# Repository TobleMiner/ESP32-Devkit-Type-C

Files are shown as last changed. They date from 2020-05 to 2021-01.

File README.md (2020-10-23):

ESP32 Devkit Type C
===================

This PCB is a USB Type C enabled ESP32 development board. It is pin-compatible
with the ESP32 Devkit C but sports a slightly decreased width to fit on a
standard breadboard.  
The current revision (Rev E) has been tested and confirmed to work fine.

# Features

* USB Type C
* pin-compatible with ESP32 Devkit
* fits on standard breadboard
* onboard antenna
* jumper to short USB protection diode

Furthermore this board is optimized for JLCPCB assembly, a Chinese SMT PCB
assembly service. All components on this board, except the USB Type C connector,
the push buttons and the pin headers can be assembled by them for around ~$8
including PCB manufacturing and components.

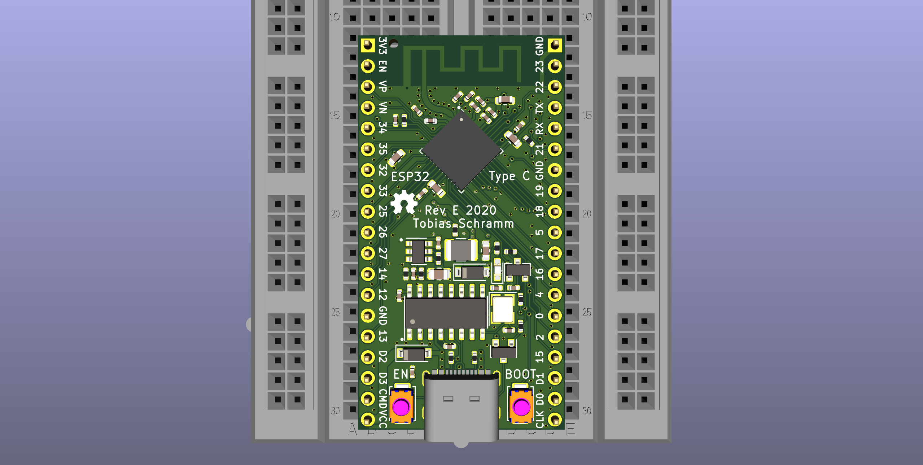
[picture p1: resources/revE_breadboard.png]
Devkit on breadboard


# Assembly

There is an
[interactive HTML BOM](https://tobleminer.github.io/ESP32-Devkit-Type-C/ibom.html)
to help you assemble the board.

Assuming you are using JLCPCB SMT assembly you will need to populate just the
following parts by hand:

| Reference  | Description | LCSC |
|---|---|---|
| J1 | USB Type C connector | [C167321](https://lcsc.com/product-detail/USB-Connectors_Jing-Extension-of-the-Electronic-Co-C167321_C167321.html) |
| SW1, SW2 | RESET/BOOT push button | [C115357](https://lcsc.com/product-detail/Tactile-Switches_ALPS_SKRKAEE020_3-4-2-1-57N_C115357.html) |
| J2, J3 | Pin headers | [C2337](https://lcsc.com/product-detail/Pin-Header-Female-Header_BOOMELE-Boom-Precision-Elec-2-54mm-1x40P_C2337.html) |

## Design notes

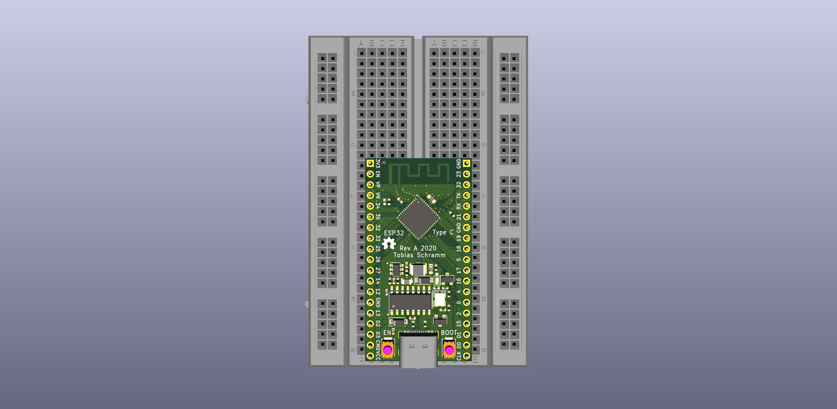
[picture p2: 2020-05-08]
resources/revA_breadboard.png

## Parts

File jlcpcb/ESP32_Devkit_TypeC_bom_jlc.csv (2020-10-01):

Comment | Designator | Footprint | LCSC Part #
10 nF | C1 | C_0402_1005Metric | C15195
22 pF | C2,C4 | C_0402_1005Metric | C1555
10 uF | C3 | C_0805_2012Metric | C15850
100 nF | C5,C7,C14,C15,C16,C6,C18,C17 | C_0402_1005Metric | C1525
22 uF | C8,C13,C24 | C_0603_1608Metric | C59461
1uF | C12 | C_0402_1005Metric | C52923
10uF | C19,C21,C20,C22 | C_0402_1005Metric | C15525
10uF | C23,C25 | C_0603_1608Metric | C19702
B5819W | D2,D1 | D_SOD-123 | C8598
LED | D3 | LED_0603_1608Metric_Castellated | C2286
USB_C_Receptacle_USB2.0 | J1 | USB_C_Receptacle_Palconn_UTC16-G | C167321
4.7 uH | L1 | L_1210_3225Metric | C86070
SS8050 | Q2,Q1 | SOT-23 | C2150
100 kR | R1,R10 | R_0402_1005Metric | C25741
5.1 kR | R3,R2 | R_0402_1005Metric | C25905
330 R | R4,R11,R12 | R_0402_1005Metric | C25104
49.9kR | R5 | R_0402_1005Metric | C25897
15 kR | R6 | R_0402_1005Metric | C25756
5.1kR | R8,R9,R7 | R_0402_1005Metric | C25905
EN | SW1 | SW_Push_SPST_NO_Alps_SKRK | C115357
BOOT | SW2 | SW_Push_SPST_NO_Alps_SKRK | C115357
MP2359 | U1 | SOT-23-6 | C14259
CH340G | U2 | SOIC-16_3.9x9.9mm_P1.27mm | C14267
ESP32-PICO-D4 | U3 | ESP32-Pico-D4 | C193707
12MHz | Y1 | Crystal_SMD_3225-4Pin_3.2x2.5mm | C9002

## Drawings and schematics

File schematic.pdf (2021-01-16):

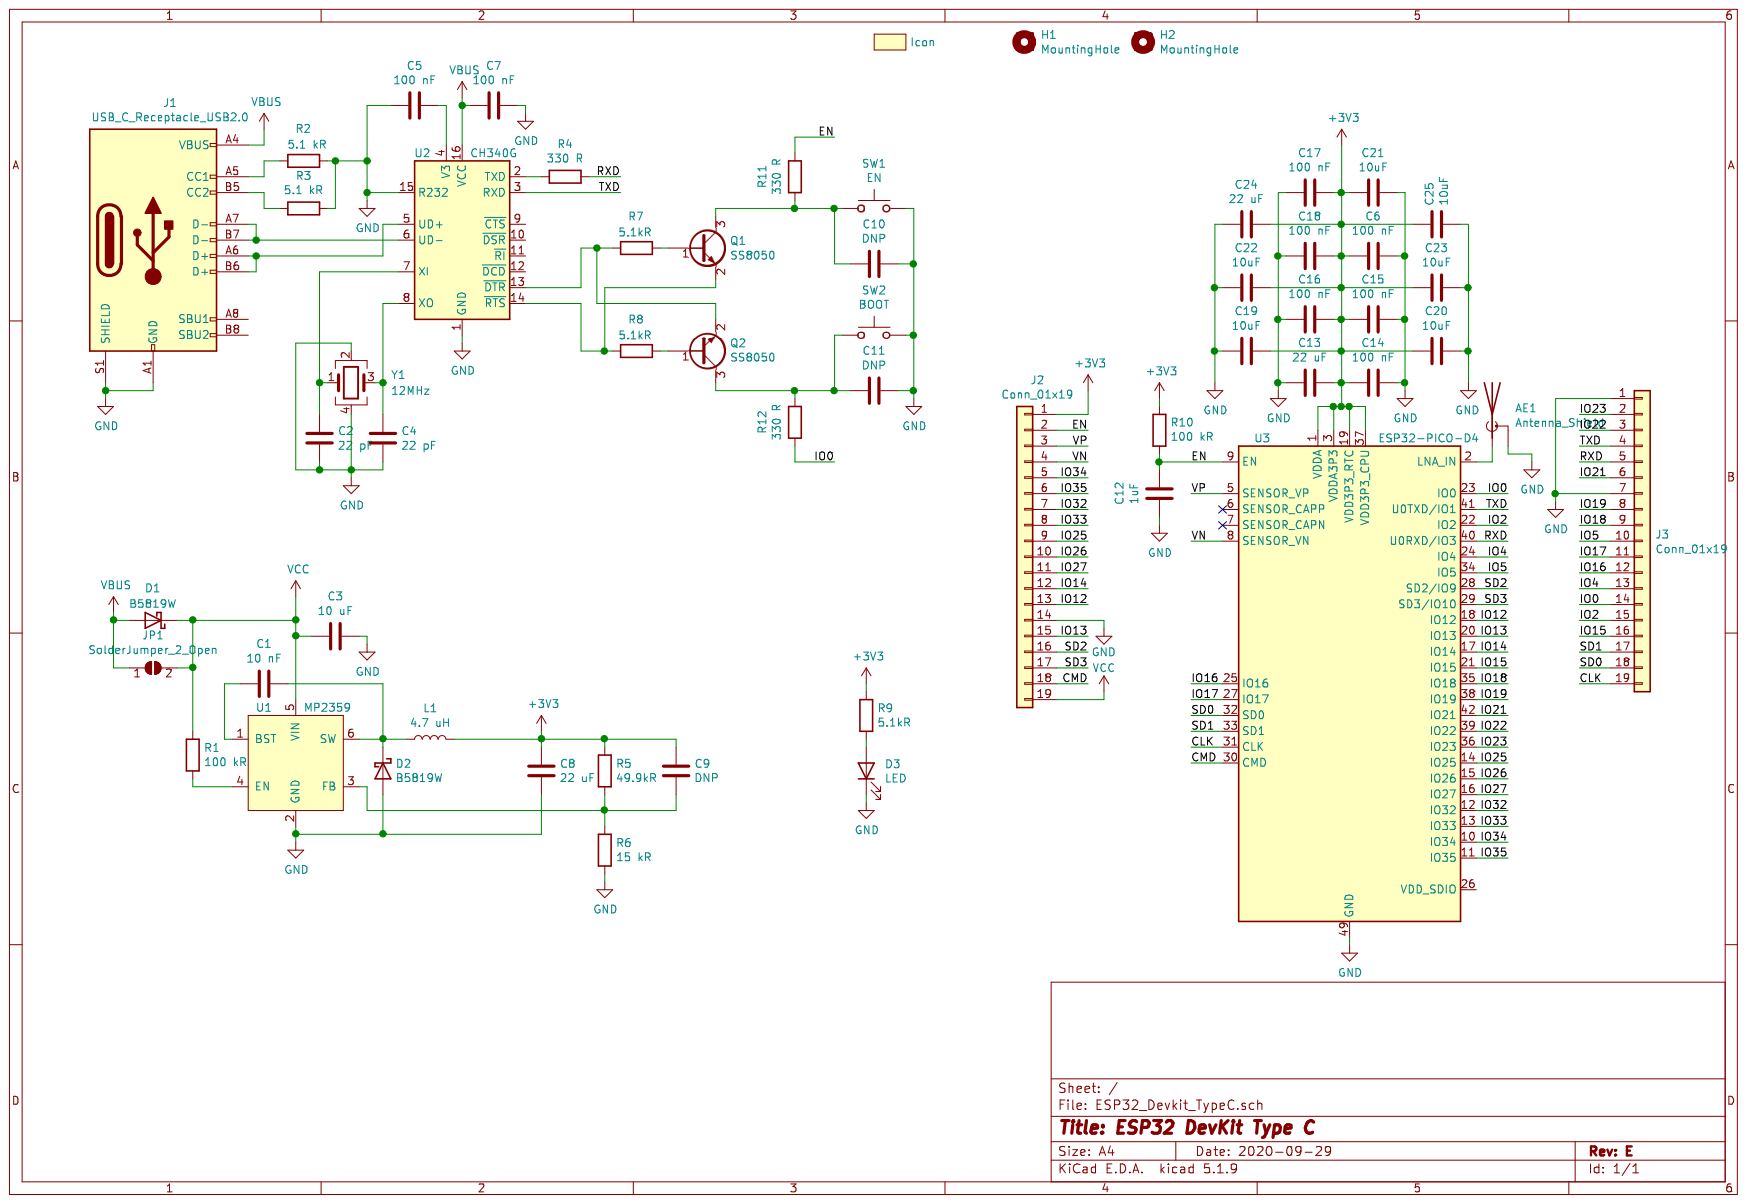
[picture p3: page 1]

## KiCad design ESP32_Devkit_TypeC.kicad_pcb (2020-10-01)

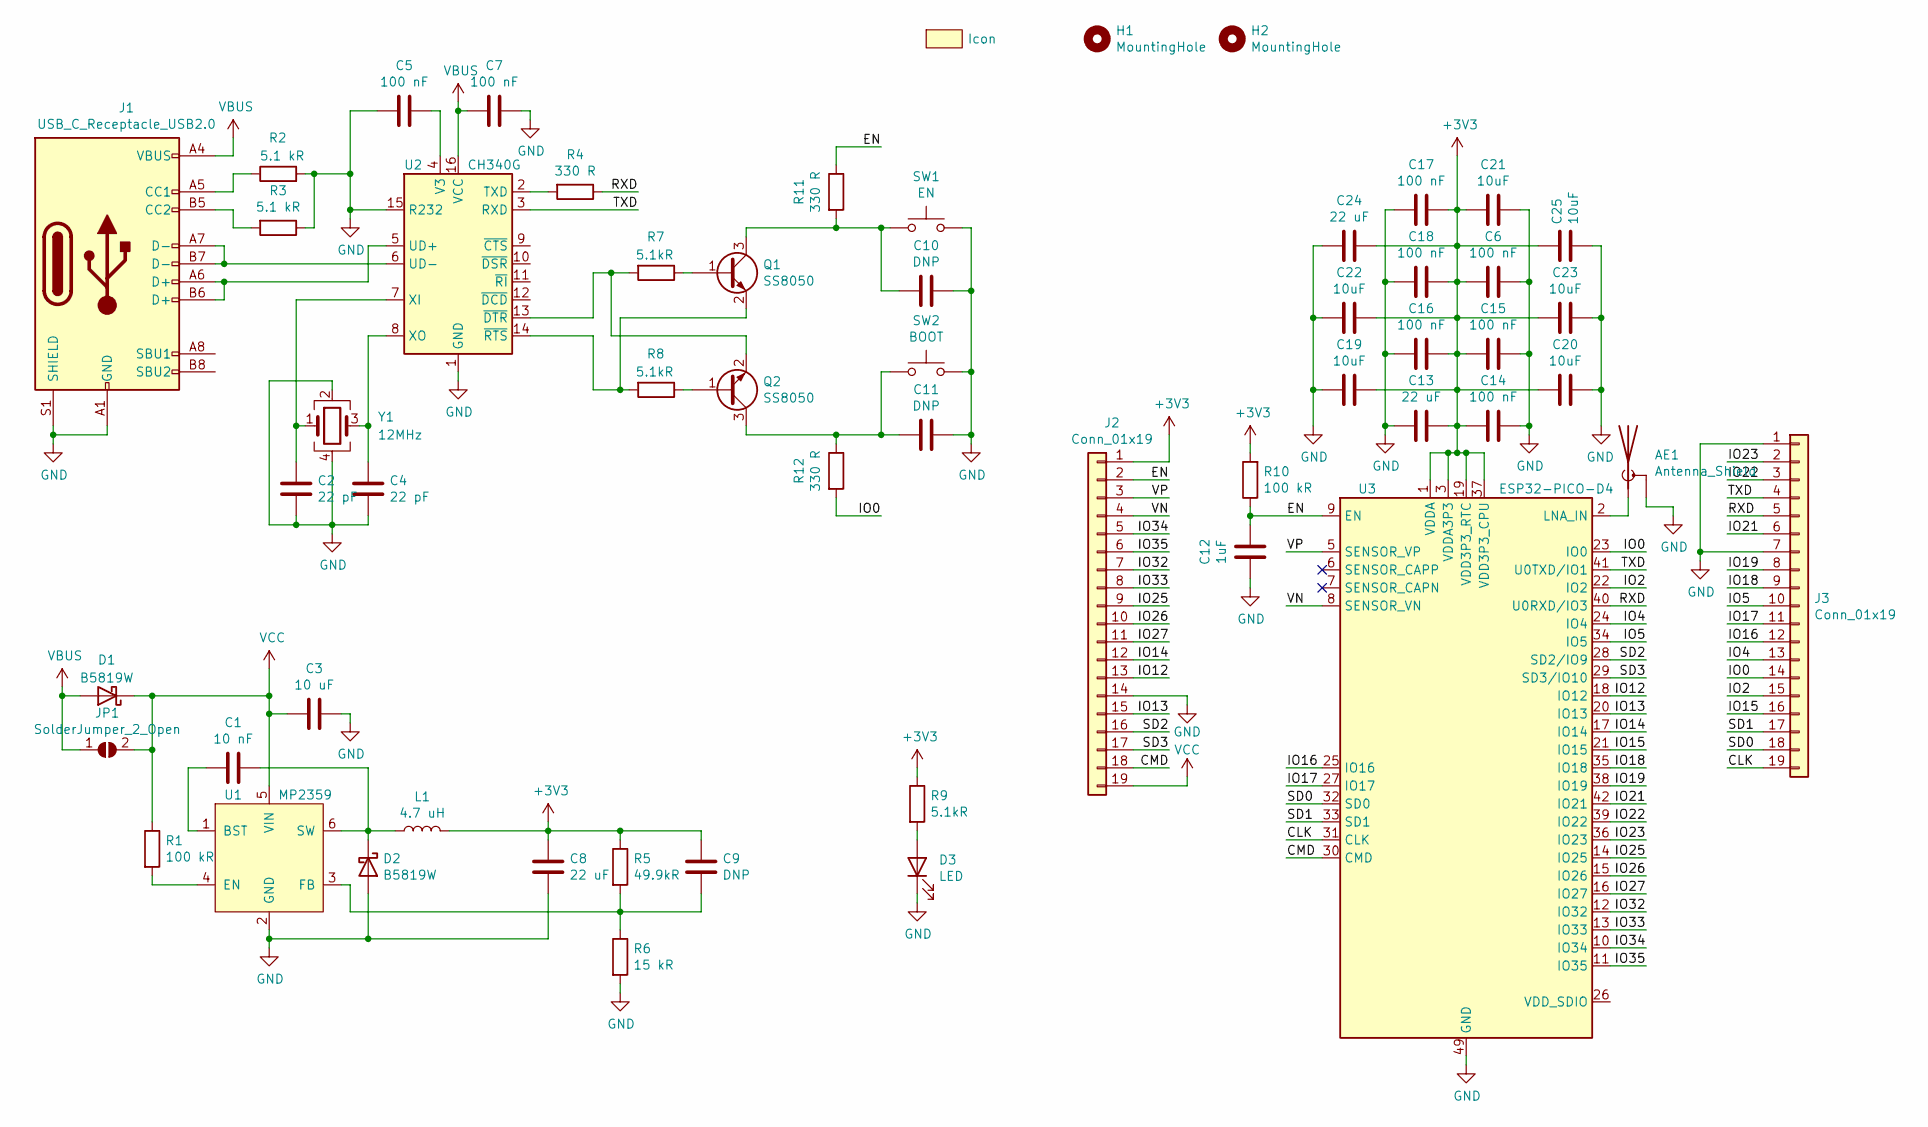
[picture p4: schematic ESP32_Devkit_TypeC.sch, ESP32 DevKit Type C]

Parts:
AE1: Antenna_Shield; Antenna_IFA_2.4GHz_meandered
C1: 10 nF; C_0402_1005Metric; LCSC C15195
C2, C4: 22 pF; C_0402_1005Metric; LCSC C1555
C3: 10 uF; C_0805_2012Metric; LCSC C15850
C5, C6, C7, C14, C15, C16, C17, C18: 100 nF; C_0402_1005Metric; LCSC C1525
C8, C13, C24: 22 uF; C_0603_1608Metric; LCSC C59461
C9, C10, C11: DNP; C_0402_1005Metric
C12: 1uF; C_0402_1005Metric; LCSC C52923
C19, C20, C21, C22: 10uF; C_0402_1005Metric; LCSC C15525
C23, C25: 10uF; C_0603_1608Metric; LCSC C19702
D1, D2: B5819W; D_SOD-123; LCSC C8598
D3: LED; LED_0603_1608Metric_Castellated; LCSC C2286
H1, H2: MountingHole; ToolingHole_JLCSMT
I2: Icon; OSHW_icon_3.3x3
J1: USB_C_Receptacle_USB2.0; USB_C_Receptacle_Palconn_UTC16-G; LCSC C167321
J2, J3: Conn_01x19; PinHeader_1x19_P2.54mm_Vertical
JP1: SolderJumper_2_Open; SolderJumper-2_P1.3mm_Open_Pad1.0x1.5mm
L1: 4.7 uH; L_1210_3225Metric; LCSC C86070
Q1, Q2: SS8050; SOT-23; LCSC C2150
R1, R10: 100 kR; R_0402_1005Metric; LCSC C25741
R2, R3: 5.1 kR; R_0402_1005Metric; LCSC C25905
R4, R11, R12: 330 R; R_0402_1005Metric; LCSC C25104
R5: 49.9kR; R_0402_1005Metric; LCSC C25897
R6: 15 kR; R_0402_1005Metric; LCSC C25756
R7, R8, R9: 5.1kR; R_0402_1005Metric; LCSC C25905
SW1: EN; SW_Push_SPST_NO_Alps_SKRK; LCSC C115357
SW2: BOOT; SW_Push_SPST_NO_Alps_SKRK; LCSC C115357
U1: MP2359; SOT-23-6; LCSC C14259
U2: CH340G; SOIC-16_3.9x9.9mm_P1.27mm; LCSC C14267
U3: ESP32-PICO-D4; ESP32-Pico-D4; LCSC C193707
Y1: 12MHz; Crystal_SMD_3225-4Pin_3.2x2.5mm; LCSC C9002

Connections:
+3V3: C6.2, C8.1, C9.1, C13.1, C14.2, C15.2, C16.1, C17.1, C18.1, C19.1, C20.2, C21.2, C22.1, C23.2, C24.1, C25.1, J2.1, L1.2, R5.1, R9.1, R10.2, U3.1 (VDDA), U3.3 (VDDA3P3), U3.4 (VDDA3P3), U3.19 (VDD3P3_RTC), U3.37 (VDD3P3_CPU), U3.43 (VDDA), U3.46 (VDDA)
/CLK: J3.19, U3.31 (CLK)
/CMD: J2.18, U3.30 (CMD)
/EN: C12.1, J2.2, R10.1, R11.1, U3.9 (EN)
/IO0: J3.14, R12.2, U3.23 (IO0)
/IO2: J3.15, U3.22 (IO2)
/IO4: J3.13, U3.24 (IO4)
/IO5: J3.10, U3.34 (IO5)
/IO12: J2.13, U3.18 (IO12)
/IO13: J2.15, U3.20 (IO13)
/IO14: J2.12, U3.17 (IO14)
/IO15: J3.16, U3.21 (IO15)
/IO16: J3.12, U3.25 (IO16)
/IO17: J3.11, U3.27 (IO17)
/IO18: J3.9, U3.35 (IO18)
/IO19: J3.8, U3.38 (IO19)
/IO21: J3.6, U3.42 (IO21)
/IO22: J3.3, U3.39 (IO22)
/IO23: J3.2, U3.36 (IO23)
/IO25: J2.9, U3.14 (IO25)
/IO26: J2.10, U3.15 (IO26)
/IO27: J2.11, U3.16 (IO27)
/IO32: J2.7, U3.12 (IO32)
/IO33: J2.8, U3.13 (IO33)
/IO34: J2.5, U3.10 (IO34)
/IO35: J2.6, U3.11 (IO35)
/RXD: J3.5, R4.1, U3.40 (U0RXD/IO3)
/SD0: J3.18, U3.32 (SD0)
/SD1: J3.17, U3.33 (SD1)
/SD2: J2.16, U3.28 (SD2/IO9)
/SD3: J2.17, U3.29 (SD3/IO10)
/TXD: J3.4, U2.3 (RXD), U3.41 (U0TXD/IO1)
/VN: J2.4, U3.8 (SENSOR_VN)
/VP: J2.3, U3.5 (SENSOR_VP)
GND: AE1.2 (Shield), C2.2, C3.1, C4.2, C5.2, C6.1, C7.1, C8.2, C10.1, C11.1, C12.2, C13.2, C14.1, C15.1, C16.2, C17.2, C18.2, C19.2, C20.1, C21.1, C22.2, C23.1, C24.2, C25.2, D2.2 (A), D3.1 (K), J1.A1 (GND), J1.A12 (GND), J1.B1 (GND), J1.B12 (GND), J1.S1 (SHIELD), J2.14, J3.1, J3.7, R2.2, R3.1, R6.2, SW1.2, SW2.2, U1.2 (GND), U2.1 (GND), U2.15 (R232), U3.49 (GND), Y1.2, Y1.4
unnamed: AE1.1 (A), U3.2 (LNA_IN)
unnamed: C1.1, D2.1 (K), L1.1, U1.6 (SW)
unnamed: C1.2, U1.1 (BST)
unnamed: C2.1, U2.7 (XI), Y1.1
unnamed: C4.1, U2.8 (XO), Y1.3
unnamed: C5.1, U2.4 (V3)
unnamed: C9.2, R5.2, R6.1, U1.3 (FB)
unnamed: C10.2, Q1.3 (C), R11.2, SW1.1
unnamed: C11.2, Q2.3 (C), R12.1, SW2.1
unnamed: D3.2 (A), R9.2
unnamed: J1.A5 (CC1), R2.1
unnamed: J1.A6 (D+), J1.B6 (D+), U2.5 (UD+)
unnamed: J1.A7 (D-), J1.B7 (D-), U2.6 (UD-)
unnamed: J1.B5 (CC2), R3.2
unnamed: Q1.1 (B), R7.1
unnamed: Q1.2 (E), R8.2, U2.14 (~RTS)
unnamed: Q2.1 (B), R8.1
unnamed: Q2.2 (E), R7.2, U2.13 (~DTR)
unnamed: R1.2, U1.4 (EN)
unnamed: R4.2, U2.2 (TXD)
VBUS: C7.2, D1.2 (A), J1.A4 (VBUS), J1.A9 (VBUS), J1.B4 (VBUS), J1.B9 (VBUS), JP1.1 (A), U2.16 (VCC)
VCC: C3.2, D1.1 (K), J2.19, JP1.2 (B), R1.1, U1.5 (VIN)

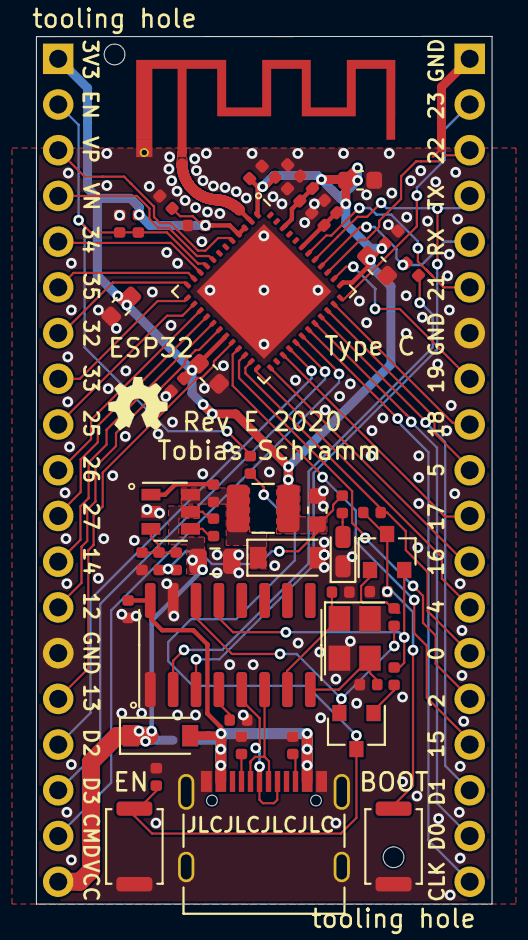
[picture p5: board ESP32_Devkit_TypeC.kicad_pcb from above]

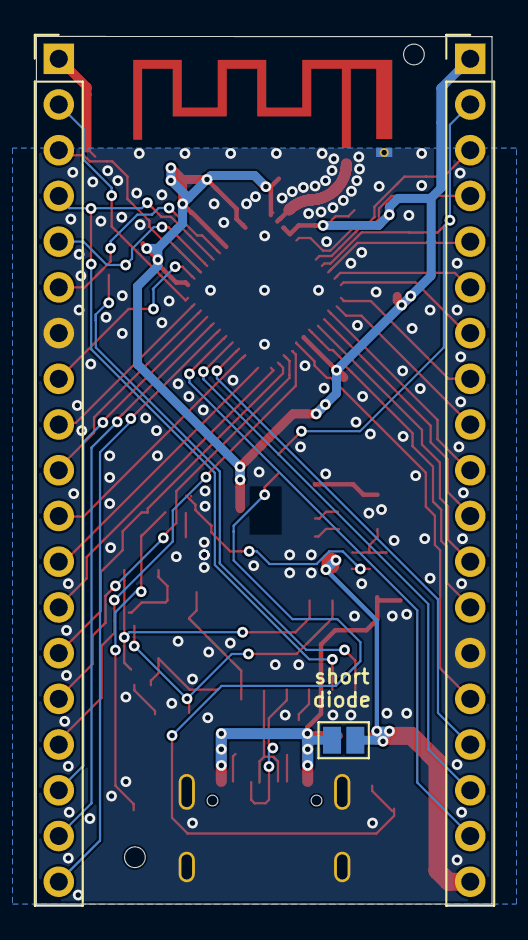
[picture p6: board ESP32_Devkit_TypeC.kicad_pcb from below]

Board: 2 copper layers, 25.3 x 48.2 mm, 57 parts (3 on the bottom side), 57 nets.

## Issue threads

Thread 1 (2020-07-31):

wrong link

psyhlo, 2020-07-31:
for
SW1, SW2 | RESET/BOOT push button | C115357
the link is wrong
i think this is the right link
https://lcsc.com/product-detail/Tactile-Switches_ALPS-Electric-SKRKAEE020_C115357.html

TobleMiner, 2020-09-07:
Yes, absolutely. Fixed by #2

Closed 2020-09-07.

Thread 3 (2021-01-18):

Antenna info

jneiva08, 2021-01-18:
@TobleMiner , congratulations for nice work.
Where can find more information about the antennas you have?

Thanks

TobleMiner, 2021-01-19:
Hi!

The antenna used is describes in TI application note AN043:
https://www.ti.com/lit/an/swra117d/swra117d.pdf?ts=1610958486456

Xathar <notifications@github.com> schrieb am Mo. 18. Jan. 2021 um 01:57:

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

matt-42, 2022-01-07:
Hi @TobleMiner
I always see a matching circuit between the antenna and the LNA pin on other boards, why this board does not have one ? Does the wifi and bluetooth works properly ?

Thanks

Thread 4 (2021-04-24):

JLCPCB Unavailable Part/Suggestions

PWN-GH, 2021-04-24:
- LQH32CN4R7M23L Inductor is on "inventory shortage" and is currently unavailable for SMT assembly.
- The MP2359 is just listed as No part selected.
- I found some USB 2.0 type C connectors that can probably be used:
[](https://lcsc.com/product-detail/USB-Connectors_SHOU-HAN-TYPE-C-DT6P-DIP_C456010.html)
[](https://lcsc.com/product-detail/USB-Connectors_Jing-Extension-of-the-Electronic-Co-918-418K2022Y40001_C399924.html)
[](https://lcsc.com/product-detail/USB-Connectors_Shenzhen-Kinghelm-Elec-KH-TYPE-C-6P_C709355.html)
[](https://lcsc.com/product-detail/USB-Connectors_SHOU-HAN-TYPE-C-6P-073_C668623.html)
- AFAIK the CH340G can be replaced with the pin-compatible recommended-part-class CH340C, then the external oscillator crystal and capacitors  can be removed because the CH340C has them built in.
-The switches showed up as assembly-ready.

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

I have no idea if these are good suggestions or not as I have zero experience in PCB design.
Thank you for making this project!

moucha19, 2022-03-13:
For anyone interested in solution to mentioned issues, I made a fork with slight changes that could help. You can find it [here](https://github.com/moucha19/ESP32-Devkit-Type-C).

Closed 2022-06-04.

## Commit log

2020-05-07 Increase strength of step down enable pullup
    [ESP32_Devkit_TypeC.sch]
2020-05-07 Hide all silkscreen references
    [ESP32_Devkit_TypeC.kicad_pcb]
2020-05-07 Add silkscreen markings
    [ESP32_Devkit_TypeC.kicad_pcb]
2020-05-07 Add tooling holes
    [ESP32_Devkit_TypeC.kicad_pcb, ESP32_Devkit_TypeC.sch]
2020-05-07 Reduce paste size by two percent
    [ESP32_Devkit_TypeC.kicad_pcb]
2020-05-08 Add more vias to VBUS
    [ESP32_Devkit_TypeC.kicad_pcb]
2020-05-08 Add screenshot of board
2020-05-08 Add OSHW logo
    [ESP32_Devkit_TypeC.kicad_pcb, ESP32_Devkit_TypeC.sch]
2020-05-08 Add 3rdparty lib folder
    [ESP32_Devkit_TypeC.kicad_pcb]
2020-05-08 Add fabrication files
    [ESP32_Devkit_TypeC-B_Cu.gbl, ESP32_Devkit_TypeC-B_Mask.gbs, ESP32_Devkit_TypeC-B_Paste.gbp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]
2020-05-08 Add interactive BOM
2020-05-08 Add assembly information
2020-05-19 Add ESP32 Pico D4 package
    The ESP32 Pico D4 is not a QFN part. It is a LGA part featuring the same
    pad locations as a QFN-48 7x7 0.5mm pitch part.
2020-05-19 Use ESP32 Pico D4 footprint
    [ESP32_Devkit_TypeC.kicad_pcb, ESP32_Devkit_TypeC.sch]
2020-05-20 Rev B
    Changes from Rev A:
    - Fix ESP32 Pico D4 footprint, now LGA
    - Add couple capacitor from EN to IO0
    - Add protection resistors to EN and IO0
    - Move VBUS diode for easier USB Type C jack assembly
    - Small routing optimizations
    [ESP32_Devkit_TypeC-B_Cu.gbl, ESP32_Devkit_TypeC-B_Mask.gbs, ESP32_Devkit_TypeC-B_Paste.gbp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]
2020-05-21 Update JLC gerbers to Rev B
2020-05-31 Fix step down GND routing
    [ESP32_Devkit_TypeC.kicad_pcb]
2020-05-31 Rev C
    Changes from Rev B:
    * Add more bypassing to ESP32 Pico D4
    * Reduce ground loop area of step-down significantly
    * Fix ugly routing of USB D+
    [ESP32_Devkit_TypeC-B_Cu.gbl, ESP32_Devkit_TypeC-B_Mask.gbs, ESP32_Devkit_TypeC-B_Paste.gbp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]
2020-08-03 Update README.md
    Changed the right component for the RESET/BOOT push button
2020-09-29 Remove fab directory
    [ESP32_Devkit_TypeC-B_Cu.gbl, ESP32_Devkit_TypeC-B_Mask.gbs, ESP32_Devkit_TypeC-B_Paste.gbp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]
2020-09-29 Mark printed antennas as virtual components
2020-09-29 Rev D
    Most importantly this revision improves reset/bootloader behaviour
    by increasing the RC time constant of the reset RC network considerably.
    (~50ms vs 1ms). This makes programming more reliable on machines with
    high DTR/RTS setting delays or when working with USB over IP solutions.
    Full list of changes:
    * Improve reset/flash behaviour
    * Eliminate 10k resistors
    * Reduce brightness of power led
    * Remove Corona warning
    * Remove groundplane below antenna
    * Eliminate cap from EN to IO0, causes boot issues
    * Add input diode shorting jumper
    [ESP32_Devkit_TypeC.kicad_pcb, ESP32_Devkit_TypeC.sch, ESP32_Devkit_TypeC_bom_jlc.csv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]
2020-10-01 Rev E better bypassing
    This revision improves upon the bypassing of the ESP32 Pico D4.
    The previous bypassing was not satisfactory to me and I fear it
    might cause issues under high load conditions.
    Bypassing is improved by adding an additional 10uF capacitor to
    each power pin.
    Additionally a third 22uF capacitor has been added to icrease bulk
    capacitance
    [ESP32_Devkit_TypeC.kicad_pcb, ESP32_Devkit_TypeC.sch, ESP32_Devkit_TypeC_bom_jlc.csv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]
2021-01-16 Add schematic pdf
